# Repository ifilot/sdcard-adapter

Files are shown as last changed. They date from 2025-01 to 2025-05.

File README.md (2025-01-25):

# SD-CARD Development Board

This development board simplifies interfacing with SD cards by translating 5V logic signals to 3.3V signals, making it ideal for projects using microcontrollers or systems with 5V logic levels. 

## Features
- 5V to 3.3V signal level translation
- Compatible with standard SD cards

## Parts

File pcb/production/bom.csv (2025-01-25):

Designator | Footprint | Quantity | Value | LCSC Part #
C1, C2 | 1206 | 2 | 100uF | C309030
J1 | sdcard-socket | 1 | SDCARD
J2 | CONN9_MSD-1_CUD | 1 | Micro_SD_Card_Det1 | C381082
Q1, Q2, Q3, Q4 | SOT-23 | 4 | BSS138 | C78284
RN1, RN2 | R_Array_Convex_4x0603 | 2 | 10k | C110924
U1 | SOT-223-3_TabPin2 | 1 | AMS1117-3.3 | C5346136

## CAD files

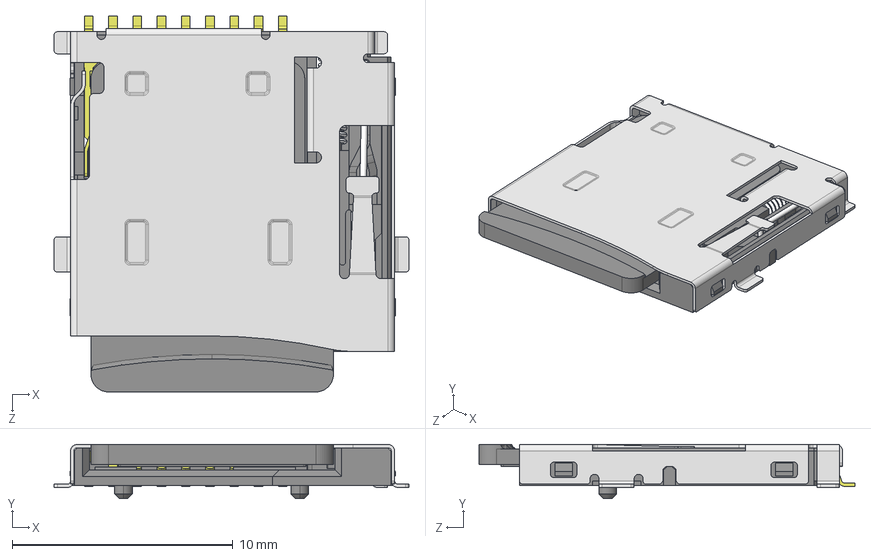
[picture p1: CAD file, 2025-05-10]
pcb/components/MicroSD_Socket.STEP
16.1 x 2.45 x 17.0 mm
Case^MicroSD_Socket
Insert^MicroSD_Socket
Brace^MicroSD_Socket
Spring^MicroSD_Socket
Lid^MicroSD_Socket
Pin_Middle^MicroSD_Socket x 5
Pin_Short^MicroSD_Socket
Pin_Long^MicroSD_Socket x 2
MicroSD_Card^MicroSD_Socket
Pin_CardIn^MicroSD_Socket

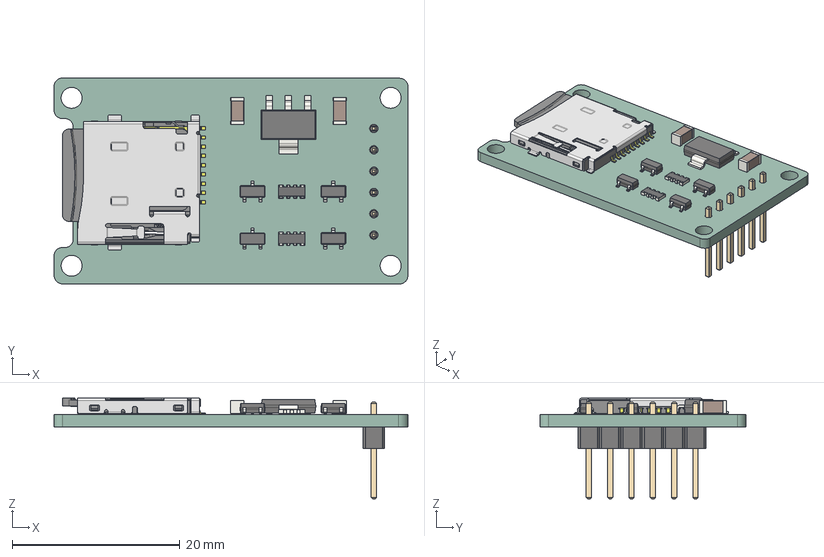
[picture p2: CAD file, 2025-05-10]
pcb/sdcard-adapter.step
42.2 x 24.5 x 12.0 mm
SOT-23 x 4
Case^MicroSD_Socket
Insert^MicroSD_Socket
Brace^MicroSD_Socket
Spring^MicroSD_Socket
Lid^MicroSD_Socket
Pin_Middle^MicroSD_Socket x 5
Pin_Short^MicroSD_Socket
Pin_Long^MicroSD_Socket x 2
MicroSD_Card^MicroSD_Socket
Pin_CardIn^MicroSD_Socket
C_1206_3216Metric x 2
R_Array_Convex_4x0603 x 2
PinHeader_1x06_P2.54mm_Vertical
SOT-223
sdcard-adapter_PCB

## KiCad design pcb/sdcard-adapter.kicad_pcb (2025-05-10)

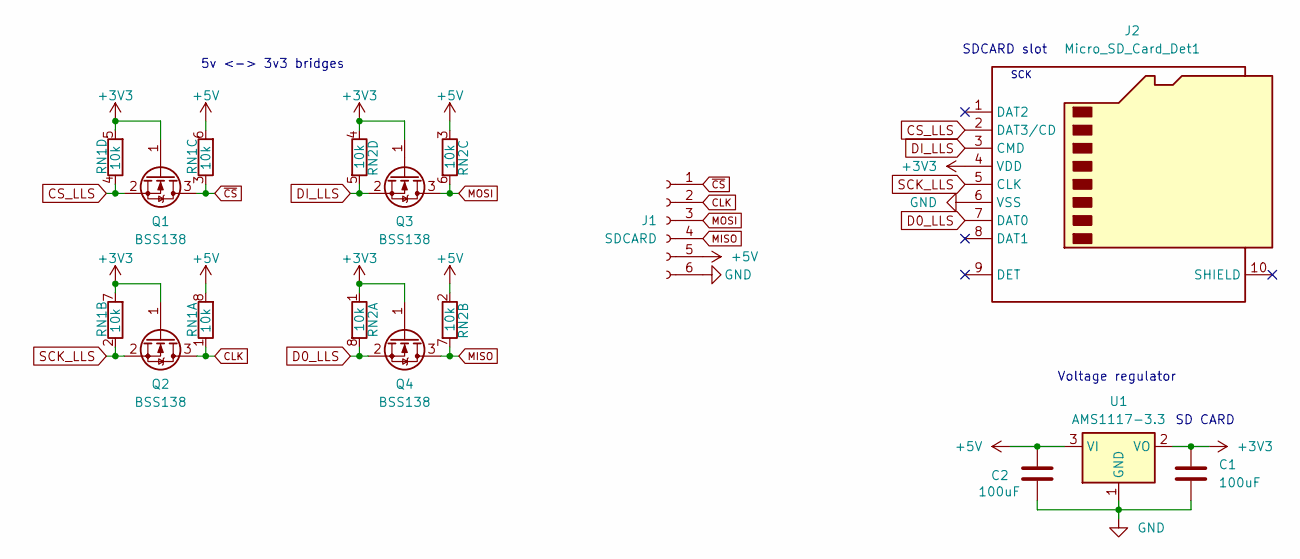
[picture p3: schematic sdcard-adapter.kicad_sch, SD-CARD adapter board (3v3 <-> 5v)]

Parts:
C1, C2: 100uF; C_1206_3216Metric_Pad1.33x1.80mm_HandSolder; LCSC Part # C309030
J1: SDCARD; PinHeader_1x06_P2.54mm_Vertical
J2: Micro_SD_Card_Det1; sdcard-socket; LCSC Part # C381082
Q1, Q2, Q3, Q4: BSS138; SOT-23; LCSC C78284
RN1, RN2: 10k; R_Array_Convex_4x0603; LCSC C110924
U1: AMS1117-3.3; SOT-223-3_TabPin2; LCSC Part # C5346136

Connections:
+3V3: C1.1, J2.4 (VDD), Q1.1 (G), Q2.1 (G), Q3.1 (G), Q4.1 (G), RN1.5 (R4.2), RN1.7 (R2.2), RN2.1 (R1.1), RN2.4 (R4.1), U1.2 (VO)
+5V: C2.1, J1.5, RN1.6 (R3.2), RN1.8 (R1.2), RN2.2 (R2.1), RN2.3 (R3.1), U1.3 (VI)
CLK: J1.2, Q2.3 (D), RN1.1 (R1.1)
CS_LLS: J2.2 (DAT3/CD), Q1.2 (S), RN1.4 (R4.1)
D0_LLS: J2.7 (DAT0), Q4.2 (S), RN2.8 (R1.2)
DI_LLS: J2.3 (CMD), Q3.2 (S), RN2.5 (R4.2)
GND: C1.2, C2.2, J1.6, J2.6 (VSS), U1.1 (GND)
MISO: J1.4, Q4.3 (D), RN2.7 (R2.2)
MOSI: J1.3, Q3.3 (D), RN2.6 (R3.2)
SCK_LLS: J2.5 (CLK), Q2.2 (S), RN1.2 (R2.1)
~CS: J1.1, Q1.3 (D), RN1.3 (R3.1)

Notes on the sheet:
SDCARD slot
SD CARD
5v <-> 3v3 bridges
Voltage regulator
SCK

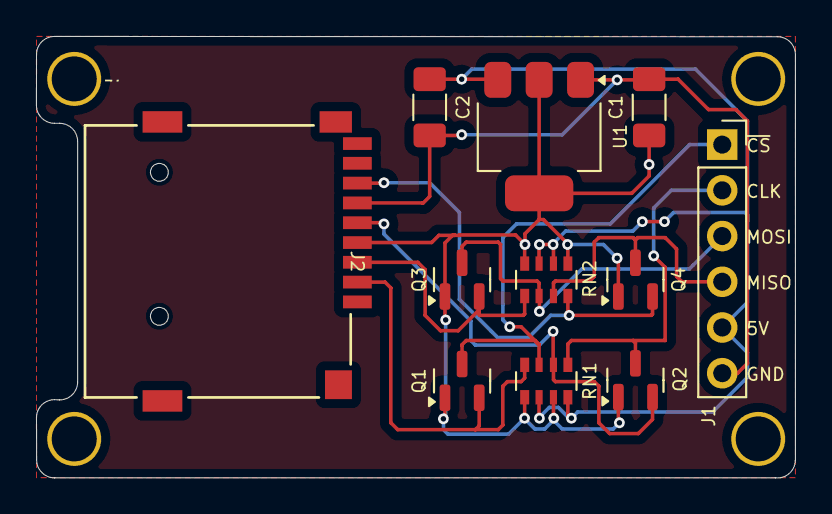
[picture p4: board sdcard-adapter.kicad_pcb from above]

Board: 2 copper layers, 42.2 x 24.5 mm, 11 parts (0 on the bottom side), 11 nets.
